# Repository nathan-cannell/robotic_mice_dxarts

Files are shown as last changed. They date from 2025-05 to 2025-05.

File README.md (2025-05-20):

# Robotic Mice DXARTS Exhibit

This repository documents the Robotic Mice project, an interactive art installation for the University of Washington's DXARTS program. The exhibit features 25 autonomous robot mice that navigate their environment, avoid human presence, and seek out darkness.

<p align="center">
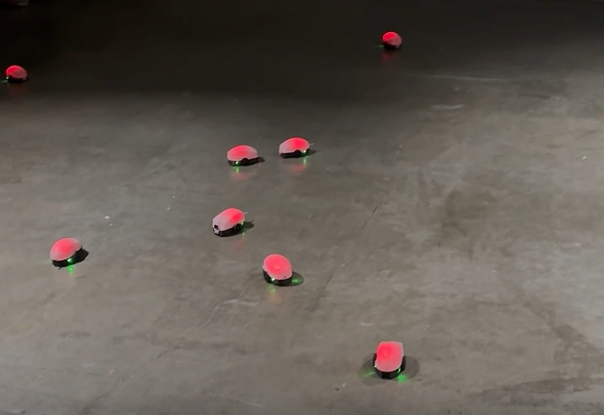
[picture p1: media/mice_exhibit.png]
  
  
  
</p>

---

## Overview

The Robotic Mice project explores the intersection of robotics, art, and emergent behavior. Each mouse is equipped with sensors and programmed to:

- Move autonomously within the exhibit space
- Avoid humans and other obstacles
- Seek out darker areas, simulating natural rodent behavior

The collective movement of the mice creates a dynamic, unpredictable environment that invites audience interaction and reflection on the boundaries between artificial and natural life.

---

## Team

| Name | Group |
|---|---|
| Sep Makhsous | ECE Professor  |
| Eunsun Choi | DXARTS Student |
| Ethan Widger | ECE Student |
| Daniela Berreth | CSE Student |
| Nathan Cannell  | ECE Student |
| Sam Han | ECE Student |
| Martin Li | ECE Student |

---

## System Architecture

The project leverages ROS 2 for distributed control and communication between the 25 robot mice. Key components include:

- **Autonomous Navigation:** Each mouse runs its own navigation stack, using sensor input to avoid obstacles and seek darkness.
- **Dynamic Namespace Assignment:** Mice are dynamically assigned unique namespaces for communication using an ID service.
- **Multi-Robot Coordination:** Centralized "mux" nodes aggregate status information (e.g., fuel/battery, presence) from all mice for monitoring and exhibit control.
- **Localization:** Each mouse runs an EKF-based localization node within its namespace to estimate its pose.

---

## Main Code Structure

### 1. Launching the System

The system is launched using ROS 2 launch files that start the ID assignment service, presence and fuel monitoring muxes, and localization nodes for each mouse.

**`mouse.launch.py` (excerpt):**
from launch import LaunchDescription
from launch_ros.actions import Node

def generate_launch_description():
ld = LaunchDescription()
mouse_id_service = Node(
    package='mouse_global',
    executable='id_service',
    name='id_service',
)
ld.add_action(mouse_id_service)

presence_mux = Node(
    package='mouse_global',
    executable='presence_mux',
    name='presence',
)
ld.add_action(presence_mux)

fuel_mux = Node(
    package='mouse_global',
    executable='fuel_monitor',
    name='fuel_monitor',
)
ld.add_action(fuel_mux)

return ld
[6]

### 2. Mouse Namespace Management

Namespaces are assigned dynamically to each mouse using a custom ROS service that ensures each robot receives a unique identifier.

**`id_srv.py` (excerpt):**
class ID_Assigner(Node):
def init(self):
super().init('mouse_global')
self.srv = self.create_service(Id, 'id_assign', self.id_request_callback)
[2]

### 3. Presence and Fuel Monitoring

Centralized mux nodes subscribe to all `/mouse_X/presence` and `/mouse_X/fuel` topics, aggregating this data for exhibit monitoring and safety.

- **PresenceMUX:** Publishes a combined presence signal and logs activity of each mouse.
- **FuelMUX:** Monitors battery levels and warns if any mouse is critically low on power.

**`presence_mux.py` and `fuel_mux.py` (excerpts):**
PresenceMUX subscribes to all /mouse_X/presence topics and publishes /presence_mux
class PresenceMUX(Node):
...
def connect(self):
mouse_topics = get_mouse_topics(self, "presence") [4]
# Subscribe to each topic

FuelMUX subscribes to all /mouse_X/fuel topics and monitors battery levels
class FuelMUX(Node):
...
def connect(self):
mouse_topics = get_mouse_topics(self, "fuel") [1]

### 4. Localization

Each mouse runs an EKF-based localization node within its namespace, as defined in `localization.launch.py`.

**`localization.launch.py` (excerpt):**
from launch import LaunchDescription
from launch_ros.actions import Node

def generate_launch_description():
ld = LaunchDescription()
mouse_namespaces = ['/mouse_1', '/mouse_2']
for namespace in mouse_namespaces:
robot_localization_node = Node(
package='robot_localization',
executable='ekf_node',
name='ekf_filter_node',
namespace=namespace)

ld.add_action(robot_localization_node)

return ld
[5]

---

## How to Run

1. **Install Dependencies:** Ensure ROS 2 and all required Python packages are installed.
2. **Build the Workspace:**
colcon build
source install/setup.bash
3. **Launch the System:**
ros2 launch mouse.launch.py
This will start the ID service, monitoring muxes, and (with additional configuration) the navigation and localization nodes for each mouse.

---

## Customization

- **Number of Mice:** The system supports dynamic scaling. Update the list of namespaces or use the ID service to add/remove mice as needed.
- **Behavior Tuning:** Modify the navigation and sensor processing scripts to adjust how mice respond to light, obstacles, or presence.

---

## Acknowledgments

This project was made possible by the collaborative efforts of students and faculty from UW's DXARTS, ECE, and CSE departments.

---

## Contact

For questions or collaboration inquiries, please contact the project team via the University of Washington DXARTS program.

---

**Enjoy exploring the emergent, collective behavior of our robotic mice!**

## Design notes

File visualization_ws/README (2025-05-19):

Gazebo:
1. ros2 launch my_bot launch_sim.launch.py

RVIZ:
1. ros2 launch my_bot rsp.launch.py
In a new terminal:
2. ros2 run joint_state_publisher_gui joint_state_publisher_gui
In another new terminal:
3. rviz2

Teleop:
1. ros2 run teleop_twist_keyboard teleop_twist_keyboard

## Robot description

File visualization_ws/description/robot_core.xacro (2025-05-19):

<?xml version="1.0"?>
<!-- source: https://articulatedrobotics.xyz/mobile-robot-2-concept-urdf/ -->

<robot xmlns:xacro="http://www.ros.org/wiki/xacro" >

    <xacro:include filename="inertial_macros.xacro"/>

    <material name="white">
        <color rgba="1 1 1 1" />
    </material>

    <material name="orange">
        <color rgba="1 0.3 0.1 1"/>
    </material>

    <material name="blue">
        <color rgba="0.2 0.2 1 1"/>
    </material>

    <material name="black">
        <color rgba="0 0 0 1"/>
    </material>

    <material name="red">
        <color rgba="1 0 0 1"/>
    </material>

    <!-- BASE LINK -->

    <link name="base_link">

    </link>


    <!-- CHASSIS LINK -->

    <joint name="chassis_joint" type="fixed">
        <parent link="base_link"/>
        <child link="chassis"/>
        <origin xyz="-0.1 0 0"/>
    </joint>

    <link name="chassis">
        <visual>
            <origin xyz="0.15 0 0.075"/>
            <geometry>
             <!-- below size dimensions are in meters -->
                <box size="0.6 0.3 0.15"/>
            </geometry>
            <material name="white"/>
        </visual>
        <collision>
            <origin xyz="0.15 0 0.075"/>
            <geometry>
                <box size="0.6 0.3 0.15"/>
            </geometry>
        </collision>
        <xacro:inertial_box mass="0.5" x="0.6" y="0.3" z="0.15"> <!-- note: mass is in kilograms-->
            <origin xyz="0.15 0 0.075" rpy="0 0 0"/>
        </xacro:inertial_box>
    </link>

    <gazebo reference="chassis">
        <material>Gazebo/White</material>
    </gazebo>

    <!-- LEFT WHEEL LINK -->
    <!-- continuous joints, as wheels should be able to rotate continuously-->

    <joint name="left_wheel_joint" type="continuous">
        <parent link="chassis"/> <!-- making the parent chassis to center the wheel-->
        <child link="left_wheel"/>
         <!-- Rotating the cylinder so that the cylinder is oriented along the y - axis (left to right)
        In ROS the default is oriented along the z axis. Need to do a quarter turn (-pi/2 radians) -->
        <origin xyz="0.15 0.175 0" rpy="-${pi/2} 0 0" />
        <!-- Here we have -pi/2 roll (rotation front to back), and zero pitch (side to side rotation), and zero yaw (vertical rotation)-->
        <axis xyz="0 0 1"/>
        <!--Wheel should point outwards, zero in x and y, and 1 in z-->
    </joint>

    <link name="left_wheel">
        <visual>
            <geometry>
                <cylinder radius="0.05" length="0.04"/>
            </geometry>
            <material name="blue"/>
        </visual>
        <collision>
            <geometry>
                <cylinder radius="0.05" length="0.04"/>
            </geometry>
        </collision>
        <xacro:inertial_cylinder mass="0.1" length="0.04" radius="0.05">
            <origin xyz="0 0 0" rpy="0 0 0"/>
        </xacro:inertial_cylinder>
    </link>

    <gazebo reference="left_wheel">
        <material>Gazebo/Blue</material>
    </gazebo>




    <!-- RIGHT WHEEL LINK -->

    <joint name="right_wheel_joint" type="continuous">
        <parent link="chassis"/> <!-- making the parent chassis to center the wheel-->
        <child link="right_wheel"/>
        <origin xyz="0.15 -0.175 0" rpy="${pi/2} 0 0" />
        <axis xyz="0 0 -1"/>
    </joint>

    <link name="right_wheel">
        <visual>
            <geometry>
                <cylinder radius="0.05" length="0.04"/>
            </geometry>
            <material name="blue"/>
        </visual>
        <collision>
            <geometry>
                <cylinder radius="0.05" length="0.04"/>
            </geometry>
        </collision>
        <xacro:inertial_cylinder mass="0.1" length="0.04" radius="0.05">
            <origin xyz="0 0 0" rpy="0 0 0"/>
        </xacro:inertial_cylinder>
    </link>

    <gazebo reference="right_wheel">
        <material>Gazebo/Blue</material>
    </gazebo>


    <!-- CASTER WHEEL LINK -->

    <joint name="caster_wheel_joint" type="fixed">
        <parent link="chassis"/>
        <child link="caster_wheel"/>
        <origin xyz="0.3 0 0"/>
    </joint>


    <link name="caster_wheel">
        <visual>
            <geometry>
                <sphere radius="0.05"/>
            </geometry>
            <material name="black"/>
        </visual>
        <collision>
            <geometry>
                <sphere radius="0.05"/>
            </geometry>
        </collision>
        <xacro:inertial_sphere mass="0.1" radius="0.05">
            <origin xyz="0 0 0" rpy="0 0 0"/>
        </xacro:inertial_sphere>
    </link>

    <gazebo reference="caster_wheel">
        <material>Gazebo/Black</material>
        <mu1 value="0.001"/>
        <mu2 value="0.001"/>
    </gazebo>

     <!-- CASTER WHEEL LINK 2 -->

    <joint name="caster_wheel_joint_2" type="fixed">
        <parent link="chassis"/>
        <child link="caster_wheel_2"/>
        <origin xyz="-0.1 0 0"/>
    </joint>

    <link name="caster_wheel_2">
        <visual>
            <geometry>
                <sphere radius="0.05"/>
            </geometry>
            <material name="black"/>
        </visual>
        <collision>
            <geometry>
                <sphere radius="0.05"/>
            </geometry>
        </collision>
        <xacro:inertial_sphere mass="0.1" radius="0.05">
            <origin xyz="0 0 0" rpy="0 0 0"/>
        </xacro:inertial_sphere>
    </link>

    <gazebo reference="caster_wheel_2">
        <material>Gazebo/Black</material>
        <mu1 value="0.001"/>
        <mu2 value="0.001"/>
    </gazebo>

</robot>

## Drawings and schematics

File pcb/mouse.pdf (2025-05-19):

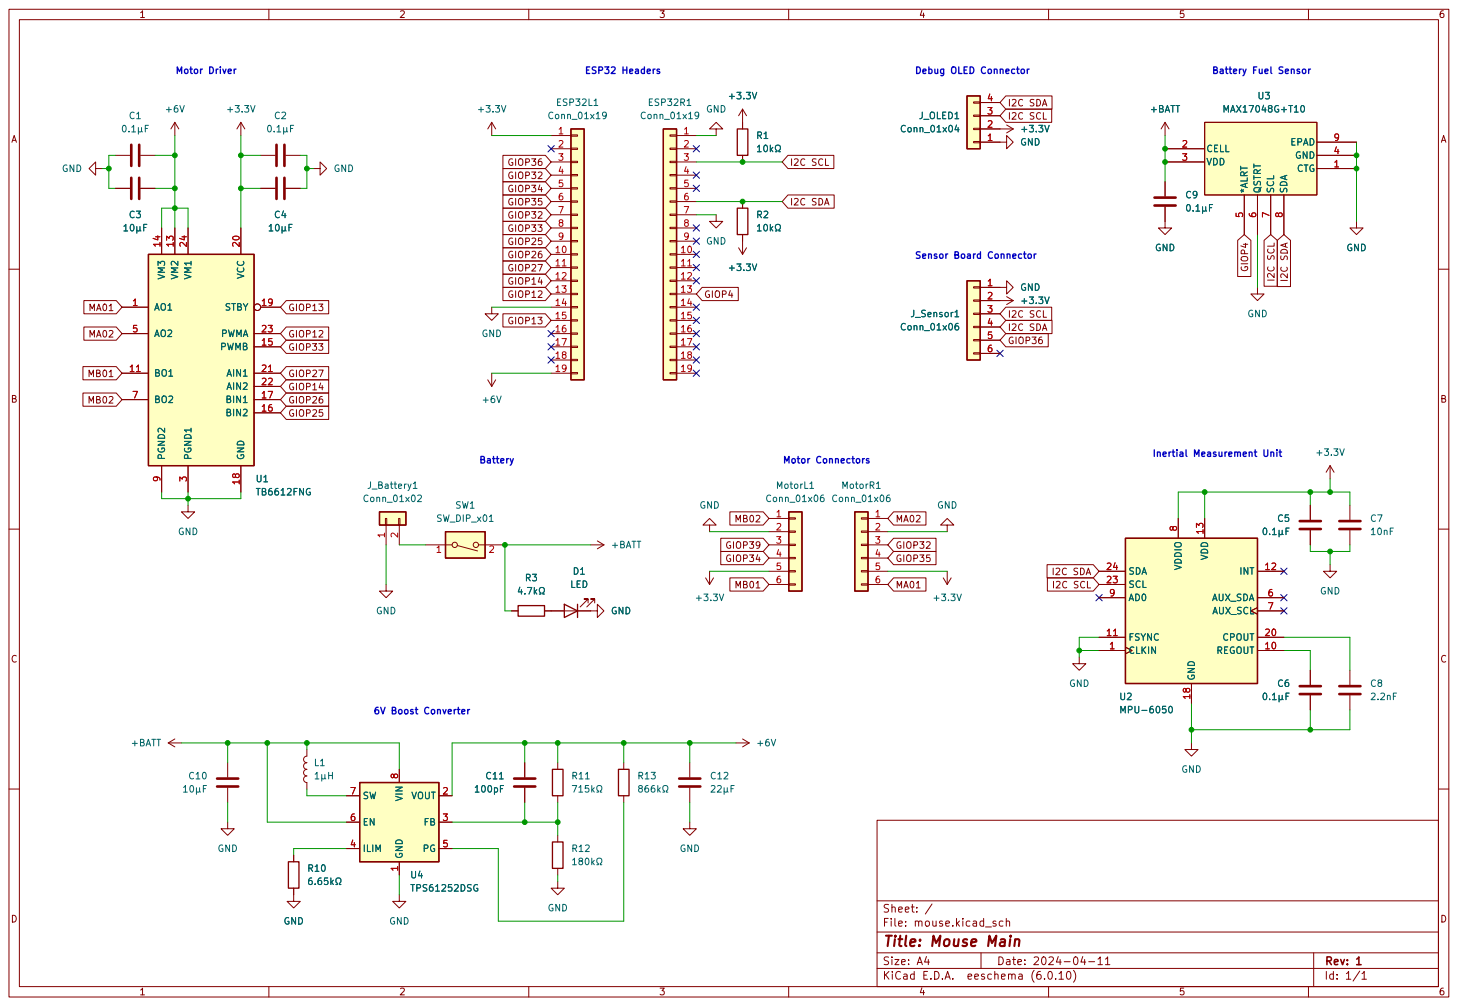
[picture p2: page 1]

8 EPAD 9 U3 MAX17048G+T10 AO1 1 BO1 11 VM2 13 VM3 14 PWMB 15 BIN2 16 BIN1 17 GND 18 STBY 19 VCC 20 AIN1 21 AIN2 22 PWMA 23 VM1 24 PGND1

Id: 1/1 Title: Mouse Main

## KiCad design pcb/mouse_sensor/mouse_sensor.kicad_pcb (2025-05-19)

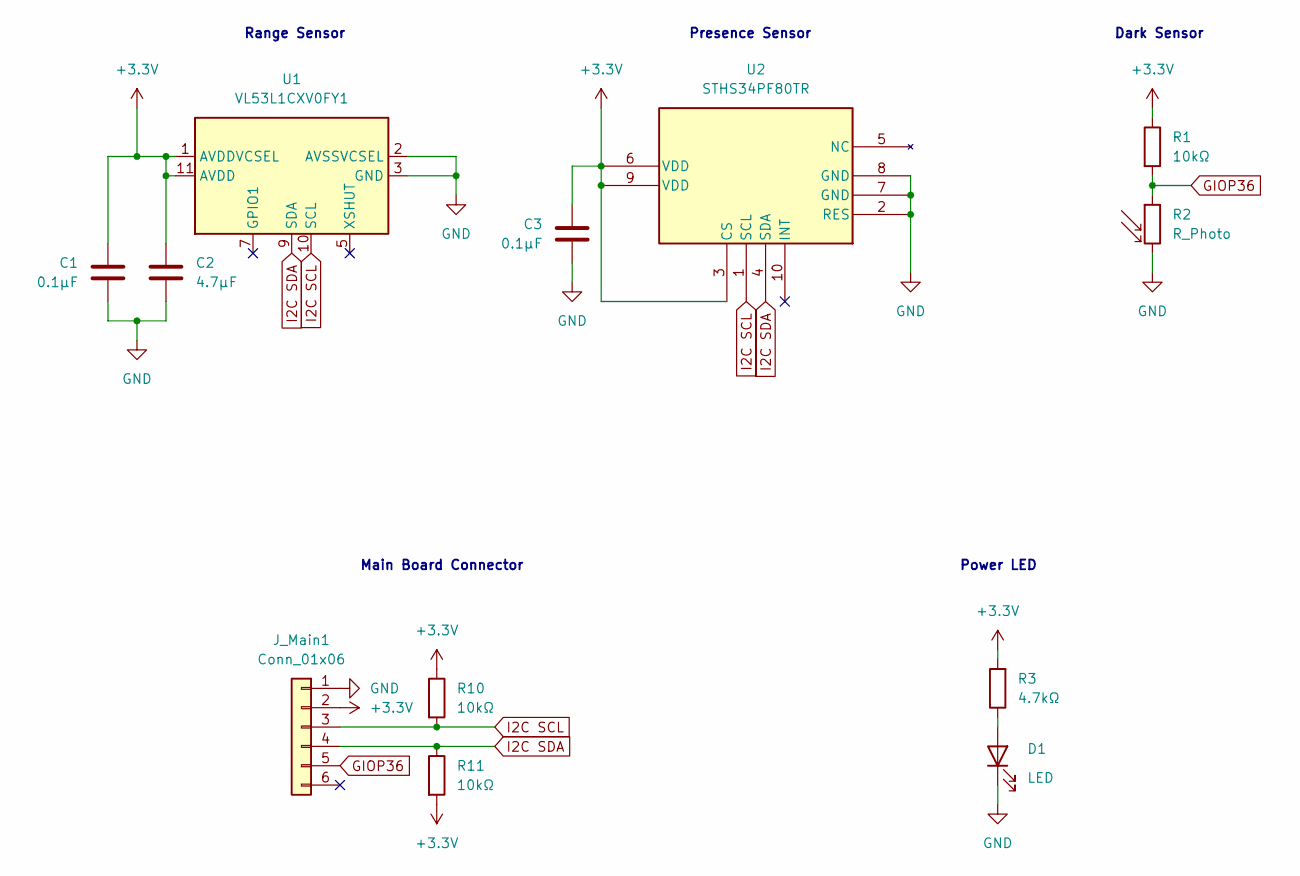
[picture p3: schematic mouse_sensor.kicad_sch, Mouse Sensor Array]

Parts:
C1, C3: 0.1µF; C_0402_1005Metric
C2: 4.7µF; C_0805_2012Metric
D1: LED; LED_0603_1608Metric
J_Main1: Conn_01x06; PinHeader_1x06_P2.54mm_Vertical
R1, R10, R11: 10kΩ; R_0603_1608Metric
R2: R_Photo; R_LDR_5.1x4.3mm_P3.4mm_Vertical
R3: 4.7kΩ; R_0603_1608Metric
U1: VL53L1CXV0FY1; ST_VL53L1x
U2: STHS34PF80TR; OLGA-10_3P2X4P2_STM

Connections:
+3.3V: C1.1, C2.1, C3.1, J_Main1.2, R1.1, R3.2, R10.1, R11.2, U1.1 (AVDDVCSEL), U1.11 (AVDD), U2.3 (CS), U2.6 (VDD), U2.9 (VDD)
GIOP36: J_Main1.5, R1.2, R2.1
GND: C1.2, C2.2, C3.2, D1.1 (K), J_Main1.1, R2.2, U1.2 (AVSSVCSEL), U1.3 (GND), U1.4 (GND), U1.6 (GND), U1.12 (GND), U2.2 (RES), U2.7 (GND), U2.8 (GND)
I2C SCL: J_Main1.3, R10.2, U1.10 (SCL), U2.1 (SCL)
I2C SDA: J_Main1.4, R11.1, U1.9 (SDA), U2.4 (SDA)
unnamed: D1.2 (A), R3.1

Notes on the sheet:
Dark Sensor
Power LED
Main Board Connector
Presence Sensor
Range Sensor

Board: 2 copper layers, 12 parts (0 on the bottom side), 6 nets, no tracks yet.

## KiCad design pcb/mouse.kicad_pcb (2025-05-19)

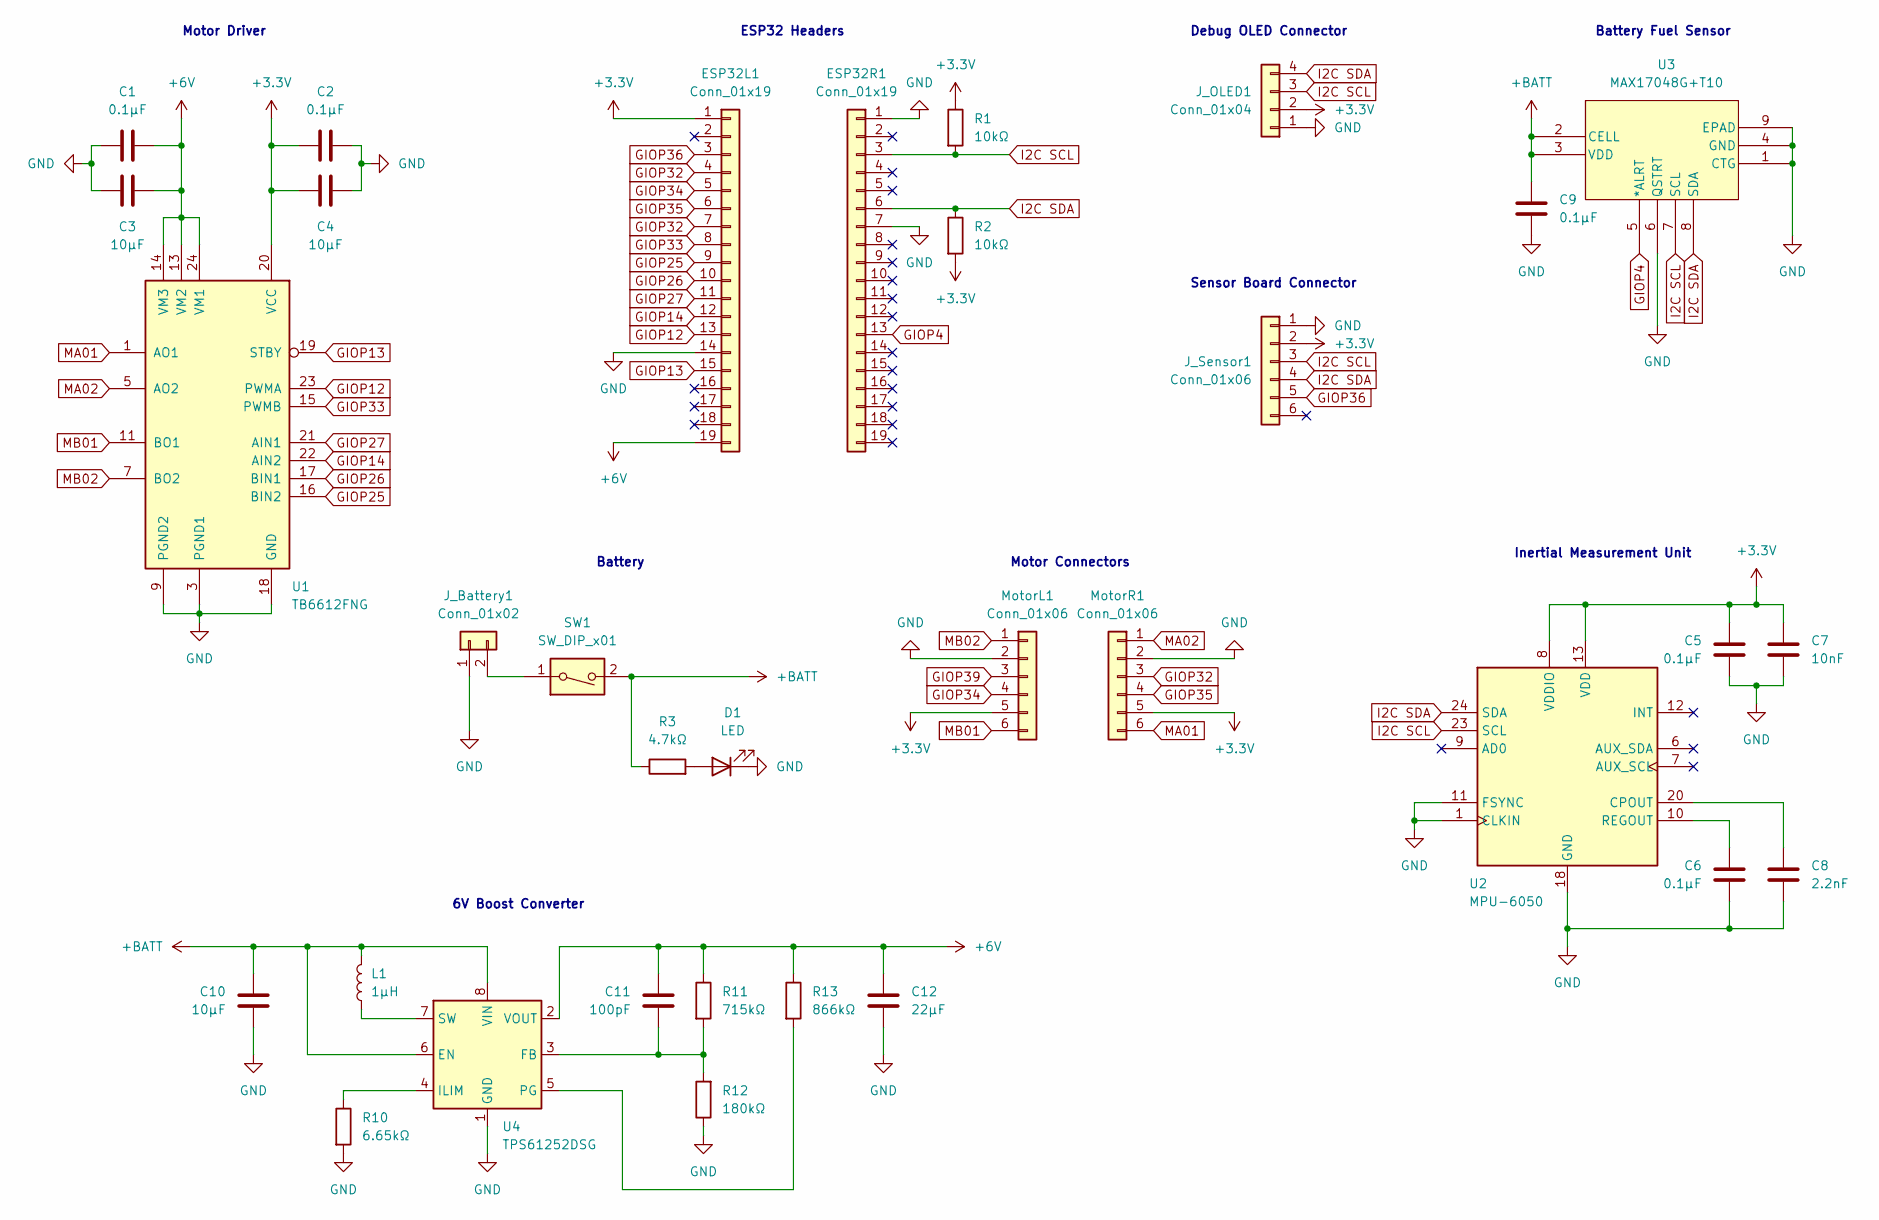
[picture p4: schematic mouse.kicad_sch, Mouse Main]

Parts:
C1, C2, C5, C6, C9: 0.1µF; C_0402_1005Metric
C3, C4, C10: 10µF; C_0603_1608Metric
C7: 10nF; C_0201_0603Metric
C8: 2.2nF; C_0603_1608Metric
C11: 100pF; C_0603_1608Metric
C12: 22µF; C_1210_3225Metric
D1: LED; LED_0603_1608Metric
ESP32L1, ESP32R1: Conn_01x19; PinSocket_1x19_P2.54mm_Vertical
J_Battery1: Conn_01x02; JST_PH_B2B-PH-K_1x02_P2.00mm_Vertical
J_OLED1: Conn_01x04; PinSocket_1x04_P2.54mm_Vertical
J_Sensor1: Conn_01x06; PinSocket_1x06_P2.54mm_Horizontal
L1: 1µH; L_0805_2012Metric
MotorL1: Conn_01x06; JST_SH_BM06B-SRSS-TB_1x06-1MP_P1.00mm_Vertical
MotorR1: Conn_01x06; JST_SH_BM06B-SRSS-TB_1x06-1MP_P1.00mm_Vertical
R1, R2: 10kΩ; R_0603_1608Metric
R3: 4.7kΩ; R_0603_1608Metric
R10: 6.65kΩ; R_0603_1608Metric
R11: 715kΩ; R_0603_1608Metric
R12: 180kΩ; R_0603_1608Metric
R13: 866kΩ; R_0603_1608Metric
SW1: SW_DIP_x01; SW_CuK_OS102011MA1QN1_SPDT_Angled
U1: TB6612FNG; SSOP-24_5.3x8.2mm_P0.65mm
U2: MPU-6050; InvenSense_QFN-24_4x4mm_P0.5mm
U3: MAX17048G+T10; 21-0168E_T822-3_MXM
U4: TPS61252DSG; WSON-8-1EP_2x2mm_P0.5mm_EP0.9x1.6mm

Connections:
+3.3V: C2.1, C4.1, C5.2, C7.1, ESP32L1.1, J_OLED1.2, J_Sensor1.2, MotorL1.5, MotorR1.5, R1.1, R2.2, U1.20 (VCC), U2.8 (VDDIO), U2.13 (VDD)
+6V: C1.1, C3.2, C11.1, C12.1, ESP32L1.19, R11.1, R13.1, U1.13 (VM2), U1.14 (VM3), U1.24 (VM1), U4.2 (VOUT)
+BATT: C9.1, C10.2, L1.2, R3.1, SW1.2, U3.2 (CELL), U3.3 (VDD), U4.6 (EN), U4.8 (VIN)
GIOP4: ESP32R1.13, U3.5 (*ALRT)
GIOP12: ESP32L1.13, U1.23 (PWMA)
GIOP13: ESP32L1.15, U1.19 (STBY)
GIOP14: ESP32L1.12, U1.22 (AIN2)
GIOP25: ESP32L1.9, U1.16 (BIN2)
GIOP26: ESP32L1.10, U1.17 (BIN1)
GIOP27: ESP32L1.11, U1.21 (AIN1)
GIOP32: ESP32L1.4, ESP32L1.7, MotorR1.3
GIOP33: ESP32L1.8, U1.15 (PWMB)
GIOP34: ESP32L1.5, MotorL1.4
GIOP35: ESP32L1.6, MotorR1.4
GIOP36: ESP32L1.3, J_Sensor1.5
GIOP39: MotorL1.3
GND: C1.2, C2.2, C3.1, C4.2, C5.1, C6.1, C7.2, C8.2, C9.2, C10.1, C12.2, D1.1 (K), ESP32L1.14, ESP32R1.1, ESP32R1.7, J_Battery1.1, J_OLED1.1, J_Sensor1.1, MotorL1.2, MotorR1.2, R10.2, R12.1, U1.3 (PGND1), U1.4 (PGND1), U1.9 (PGND2), U1.10 (PGND2), U1.18 (GND), U2.1 (CLKIN), U2.11 (FSYNC), U2.18 (GND), U3.1 (CTG), U3.4 (GND), U3.6 (QSTRT), U3.9 (EPAD), U4.1 (GND), U4.9 (GND)
I2C SCL: ESP32R1.3, J_OLED1.3, J_Sensor1.3, R1.2, U2.23 (SCL), U3.7 (SCL)
I2C SDA: ESP32R1.6, J_OLED1.4, J_Sensor1.4, R2.1, U2.24 (SDA), U3.8 (SDA)
MA01: MotorR1.6, U1.1 (AO1), U1.2 (AO1)
MA02: MotorR1.1, U1.5 (AO2), U1.6 (AO2)
MB01: MotorL1.6, U1.11 (BO1), U1.12 (BO1)
MB02: MotorL1.1, U1.7 (BO2), U1.8 (BO2)
unnamed: C6.2, U2.10 (REGOUT)
unnamed: C8.1, U2.20 (CPOUT)
unnamed: C11.2, R11.2, R12.2, U4.3 (FB)
unnamed: D1.2 (A), R3.2
unnamed: J_Battery1.2, SW1.1
unnamed: L1.1, U4.7 (SW)
unnamed: R10.1, U4.4 (ILIM)
unnamed: R13.2, U4.5 (PG)

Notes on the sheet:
Motor Connectors
ESP32 Headers
Battery Fuel Sensor
Debug OLED Connector
Motor Driver
6V Boost Converter
Battery
Sensor Board Connector
Inertial Measurement Unit

Board: 2 copper layers, 33 parts (0 on the bottom side), 30 nets, no tracks yet.

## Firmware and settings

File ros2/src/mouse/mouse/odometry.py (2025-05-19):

import rclpy
from rclpy.node import Node

from std_msgs.msg import String
from custom_msgs.msg import Encoders
from sensor_msgs.msg import Imu 
from typing import NamedTuple
from nav_msgs.msg import Odometry
import std_msgs.msg
import math

# Publisher/subscriber resources:
# https://docs.ros.org/en/humble/Tutorials/Beginner-Client-Libraries/Writing-A-Simple-Py-Publisher-And-Subscriber.html
# http://wiki.ros.org/ROS/Tutorials/CustomMessagePublisherSubscriber%28python%29
# https://ros2-tutorial.readthedocs.io/en/latest/publishers_and_subscribers.html

# Going to use a struct to store data from the subscriber:
# Structs in python: https://stackoverflow.com/questions/35988/c-like-structures-in-python
class MotorOdometryStruct(NamedTuple):
    time_stamp: float
    right_motor_counts:int
    left_motor_counts:int
    right_position: float # distance traveled for the right wheel
    left_position: float # distance traveled for the left wheel
    right_vel: float # units are in meters/s
    left_vel: float # units are in meters/s
    wheel_radius: float
    wheel_separation: float

# https://docs.ros.org/en/noetic/api/geometry_msgs/html/msg/Quaternion.html
class Vector4(NamedTuple):
    x_value: float
    y_value: float
    z_value: float
    w_value: float

class Vector3(NamedTuple):
    x_value: float
    y_value: float
    z_value: float

class OdometryInfo(Node):

    def __init__(self):
        super().__init__('mouse')
        self.get_logger().info("start of init")

        self.wheel_separation = 0.074
        self.wheel_radius = 0.0167

        # The conversion value: (revolutions per minute -> radians per second)
        self.rpm_to_radians = 0.10471975512

        # Varaibles needed for accumulate:
        self.sum_ = 0
        self.buffer_ = []
        self.next_insert_ = 0
        self.buffer_filled:bool = False

        # assuning that we start from no movement: 
        self.previousLinearAcceleration = Vector3(0, 0, 0)
        self.previousTime = self.get_clock().now().to_msg()

        # Odometry definition: https://docs.ros.org/en/noetic/api/nav_msgs/html/msg/Odometry.html
        self.odometryPublisher = self.create_publisher(
            msg_type=Odometry, topic='/mouse_1/odometry', qos_profile=10)
        self.get_logger().info("Made the odometry publisher")

        # Initializing a python dictionary to store the messages for the encoders and imu
        self.encoders_received_values:dict = {}
        #self.imu_received_values:dict = {}

        # making the subscriber for the motor encoders (to read data from '/mouse_1/encoders/')
        self.encodersSubscriber_ = self.create_subscription(
            msg_type=Encoders, 
            topic='/mouse_1/encoders', 
            callback=self.encoders_callback, 
            qos_profile=20
        )
        self.get_logger().info('made the encodersSubscriber')

        timer_period = 0.20  # seconds
        self.timer = self.create_timer(timer_period, self.timer_callback)
        self.i = 0

        self.encoders_most_recent_key = -1
        #self.imu_most_recent_key = -1

        # variables for the odometry message:
        self.odometrySequenceNumber:int = 0

        # Assuming that the initial position is the origin:
        self.pos_x:float = 0.0
        self.pos_y:float = 0.0
        self.theta:float = 0.0

        # encoder information: 
        self.counts_per_rev:int = 28

    # This should be called whenever we receive a message:
    def encoders_callback(self, encoders_msg):
        self.get_logger().info("We have entered the encoders callback")
        # See the header definition: https://docs.ros.org/en/melodic/api/std_msgs/html/msg/Header.html
        timestamp:float = encoders_msg.header.stamp.sec + encoders_msg.header.stamp.nanosec * 1e-9
        right_motor_counts:int = encoders_msg.right_motor_counts
        left_motor_counts:int = encoders_msg.left_motor_counts
        right_pos:float = encoders_msg.right_position
        left_pos:float = encoders_msg.left_position
        right_vel:float = encoders_msg.right_vel
        left_vel:float = encoders_msg.left_vel
        radius:float = self.wheel_radius
        separation_between_wheels:float = self.wheel_separation
        #self.get_logger().info("finished reading values from encoders_msg")

        # Updating the key/index: 
        self.encoders_most_recent_key =  self.encoders_most_recent_key + 1
        #self.get_logger().info('Updated the key')

        # Putting the data into our struct:
        encoders_data = MotorOdometryStruct(timestamp, right_motor_counts, left_motor_counts, right_pos, left_pos, right_vel, left_vel, radius, separation_between_wheels)

        self.encoders_received_values[self.encoders_most_recent_key] = encoders_data
        self.get_logger().info('len(self.encoders_received_values) is: %d' % len(self.encoders_received_values))

    def timer_callback(self):
        self.get_logger().info("We have entered the timer_callback ")
        # Processing our data (forming Odometry message): comparing the last two entries
        self.get_logger().info('len(self.encoders_received_values) is: ' + str(len(self.encoders_received_values)))
        if (len(self.encoders_received_values) > 1):
            current_encoder_data = self.encoders_received_values.get(self.encoders_most_recent_key)
            previous_encoder_data = self.encoders_received_values.get(self.encoders_most_recent_key - 1)
            
            # Getting distance traveled:
            right_distance = current_encoder_data.right_position
            self.get_logger().info('right_distance is: %f' % right_distance)
            left_distance = current_encoder_data.left_position
            self.get_logger().info('left is: %f' % left_distance)

            # Change in orientation:
            # TODO: check that delta_theta is correct. 
            delta_theta = (right_distance - left_distance) / self.wheel_separation
            self.get_logger().info('delta_theta is: %f' % delta_theta)

            # First half of equation: change in position (divide by 2.0 to get the midpoint between the two wheels -> straight line movement estimate)
            delta_x = (left_distance + right_distance) / 2.0 * math.cos(delta_theta) # Cosine of change in angle gets the adjacent side (x position)
            self.get_logger().info('delta_x is: %f' % delta_x)
            delta_y = (left_distance + right_distance) / 2.0 * math.sin(delta_theta) # Sine of the change in orientation gets the opposite side of the triangle (the y position)
            self.get_logger().info('delta_y is: %f' % delta_y)

            # Updating our position:
            self.pos_x  = self.pos_x + delta_x
            self.get_logger().info('pos_x is: %f' % self.pos_x)
            self.pos_y = self.pos_y + delta_y
            self.get_logger().info('pos_y is: %f' % self.pos_y)
            # Updating our orientation: 
            self.theta = self.theta + delta_theta

            # creating the header for the Odometry message:
            # https://robotics.stackexchange.com/questions/50135/what-is-the-proper-way-to-create-a-header-with-python
            # https://stackoverflow.com/questions/74976911/create-an-odometry-publisher-node-in-python-ros2
            odom = Odometry()
            odom.header = std_msgs.msg.Header()
            odom.header.stamp = self.get_clock().now().to_msg()
            odom.header.frame_id = 'odom'
            odom.child_frame_id = 'base_link'
            
            # generating the pose for the odometry message:
            odom.pose.pose.position.x = self.pos_x
            odom.pose.pose.position.y = self.pos_y
            odom.pose.pose.position.z = float(0.0)

            # Uses a quaternion as an orientation
            # See header definition: https://docs.ros.org/en/noetic/api/geometry_msgs/html/msg/Quaternion.html

            # Z in the quaternion -> imaginary component, defines the axis of rotation
            odom.pose.pose.orientation.z = math.sin(self.theta / 2.0)
            # W in the quaterian -> measurement of rotation, the real component
            odom.pose.pose.orientation.w = math.cos(self.theta / 2.0)

            # Start of linear_velocity calculations:
            delta_time = current_encoder_data.time_stamp - previous_encoder_data.time_stamp

            # linear velocity components: (x is horizontal movement, y is forward movement)
            # Total linear velocity should be the average of both wheel values
            linear_velocity_estimate_total = (current_encoder_data.right_vel + current_encoder_data.left_vel) / 2
            linear_velocity_z = float(0.0)

            # https://www.khanacademy.org/science/physics/two-dimensional-motion/two-dimensional-projectile-mot/a/what-are-velocity-components
            sin_theta = math.sin(self.theta)
            linear_velocity_y = sin_theta * linear_velocity_estimate_total
            cos_theta = math.cos(self.theta)
            linear_velocity_x = cos_theta * linear_velocity_estimate_total
            self.get_logger().info('new linear_velocity_x using theta/triganometry is: %f' % linear_velocity_x)
            self.get_logger().info('new linear_velocity_y using theta/triganometry is: %f' % linear_velocity_y)

            odom.twist.twist.linear.x = float(linear_velocity_x)
            odom.twist.twist.linear.y = float(linear_velocity_y)
            odom.twist.twist.linear.z = float(linear_velocity_z)

            # Getting the angular velocities:
            # https://automaticaddison.com/how-to-calculate-the-velocity-of-a-dc-motor-with-encoder/

            rpm_right = current_encoder_data.right_motor_counts * 60 / self.counts_per_rev
            rpm_left = current_encoder_data.left_motor_counts * 60 / self.counts_per_rev
            ang_velocity_right = rpm_right * self.rpm_to_radians
            ang_velocity_left = rpm_left * self.rpm_to_radians
            ang_velocity_z = (ang_velocity_right + ang_velocity_left) / 2

            # the x and y components should be zero as we have two-dimensional motion. 
            ang_velocity_x = float(0.0)
            ang_velocity_y = float(0.0)

            # angular velocity = change in angle / change in time. 
            # Resource: https://medium.com/@nahmed3536/wheel-odometry-model-for-differential-drive-robotics-91b85a012299
            # Supposing that we estimate the distance traveled as a straight line path,
            # the below angle would represent the change in the robot's position
            # if we formed a triangle from the starting and ending points.
            delta_alpha = delta_theta / 2; 
            # And angular velocity is the change in angular rotation over time.
            ang_velocity_z = float(delta_alpha / delta_time)
            self.get_logger().info('theta: %f' % self.theta)
            self.get_logger().info('delta_theta: %f' % delta_theta)
            self.get_logger().info('delta_alpha: %f' % delta_alpha)
            self.get_logger().info('angular velocity: %f' % ang_velocity_z)
            
            odom.twist.twist.angular.x = float(ang_velocity_x)
            odom.twist.twist.angular.y = float(ang_velocity_y)
            odom.twist.twist.angular.z = float(ang_velocity_z)

            self.odometrySequenceNumber = self.odometrySequenceNumber + 1
            self.get_logger().info("Publishing the odom now: ")

            # Publishing the data:
            self.odometryPublisher.publish(odom)      

def main(args=None):
        rclpy.init(args=args)

        odometryPublisher = OdometryInfo()
        odometryPublisher.get_logger().info('returned from call to OdometryInfo')
        
        # Keep program executing until this node has stopped.
        rclpy.spin(odometryPublisher)

if __name__ == '__main__':
        main()

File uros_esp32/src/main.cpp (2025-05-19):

/**
 * @file main.cpp
 * @author Ethan Widger
 * @brief The main launch file for the dxArts Robotic Mouse Project.
 * @version 0.1
 * @date 2024-02-28
 *
 * @copyright Copyright (c) 2024
 *
 */
#include <main.h>

/**
 * @brief Main initialization function.
 *
 */
void setup() {
  /// @brief Connection information for WiFi
  IPAddress agent_ip(192, 168, 4, 1);
  size_t agent_port = 8888;
  char ssid[] = "dxRobots";
  char psk[] = "letMe$500in";

  // Random Number
  srand(time(NULL));

  // Set up I2C
  Wire.begin();

  // Set up feedback for LED
  pinMode(OBLED_PIN, OUTPUT);
  digitalWrite(OBLED_PIN, HIGH);
  oled_setup();
  print("WiFi", "Connecting...");

// Connect to Serial Transport
#if defined(MICRO_ROS_TRANSPORT_ARDUINO_SERIAL)
  Serial.begin(115200);
  set_microros_serial_transports(Serial);
// Connect to WiFi Transport
#elif defined(MICRO_ROS_TRANSPORT_ARDUINO_WIFI)
  set_microros_wifi_transports(ssid, psk, agent_ip, agent_port);
  digitalWrite(OBLED_PIN, LOW);  // Connected to WiFi turns off LED.

  char buffer[127];
  sprintf(buffer, "Connected as\n%s", WiFi.localIP().toString());
  print("WiFi", buffer);
#else
#error "No transport defined. Check platformio.ini file."
#endif

  delay(2000);
  clear();
  delay(1000);

  node_setup();

  xTaskCreate(node_spin_task, "Node Spin", 5000, NULL, 2, NULL);
  xTaskCreate(motor_task, "Motors", 1000, NULL, 1, NULL);
}

/**
 * @brief Main loop function.
 *
 */
void loop() {}
